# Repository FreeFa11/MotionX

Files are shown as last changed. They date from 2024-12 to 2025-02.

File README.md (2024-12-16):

# MotionControl
An input device that interprets your hand movement using IMU. MPU6050 with HMC5883L will be used for taking the input from hand movement as they are widely accessible and affordable. The aim of this project is to be able to implement all the important features and gestures from mouse and trackpads. If possible, we will also try to implement a touch screen like interaction.

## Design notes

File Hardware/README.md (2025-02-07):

# Schematics
This section has three parts.

- Enclosure : A 3D printable enclosure for keeping every electronic component together.
- Schematic : An schematic made using [KiCAD](https://www.kicad.org/).
- Simulation : An schematic of [LTSpice](https://www.analog.com/en/resources/design-tools-and-calculators/ltspice-simulator.html) for simulation of components.

The 3D printed enclosure has Body and Cover which is the case for housing all the electronic components. The Ring, Slider and Base are the moving parts that moves with your fingers which is assembled as shown in Assembled.png picture. The 3D design needs some improvement for better printable, strength and assembly.

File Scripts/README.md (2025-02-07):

# Scripts
All the scripts required during the development of this project are maintained here. The scripts include data collection, manipulation, visualisation and other simulations.

- Calibration : This folder contains the static data collection of accelerometer and calculation of all the parameters for calibration.
- Data Collection : This folder contains the script to capture data from serial port and parse the JSON string and upload it to the [Edge Impulse](https://edgeimpulse.com/).
- Data Preprocessing : This folder contains the scripts for analyzing the features of data.

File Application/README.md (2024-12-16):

# Application
This android application allows us to conveniently configure the device and also change some preferences and see how well the device is working. All the settings and preferences are managed through this application.

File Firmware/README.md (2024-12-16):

# Firmware
This section covers the firmware for MotionControl project.

- Microcontroller :     [ESP32S3 (N8R2)](https://www.espressif.com/en/products/socs/esp32-s3)
- Framework :           [PlatformIO](https://platformio.org/)
- Scheduler :           [FreeRTOS](https://www.freertos.org/)

## Structure
The structure is based on PlatformIO project environment.
- lib : Project specific libraries written by us
- include : Project Header files
- src : Project Source files
- test : Unit testing

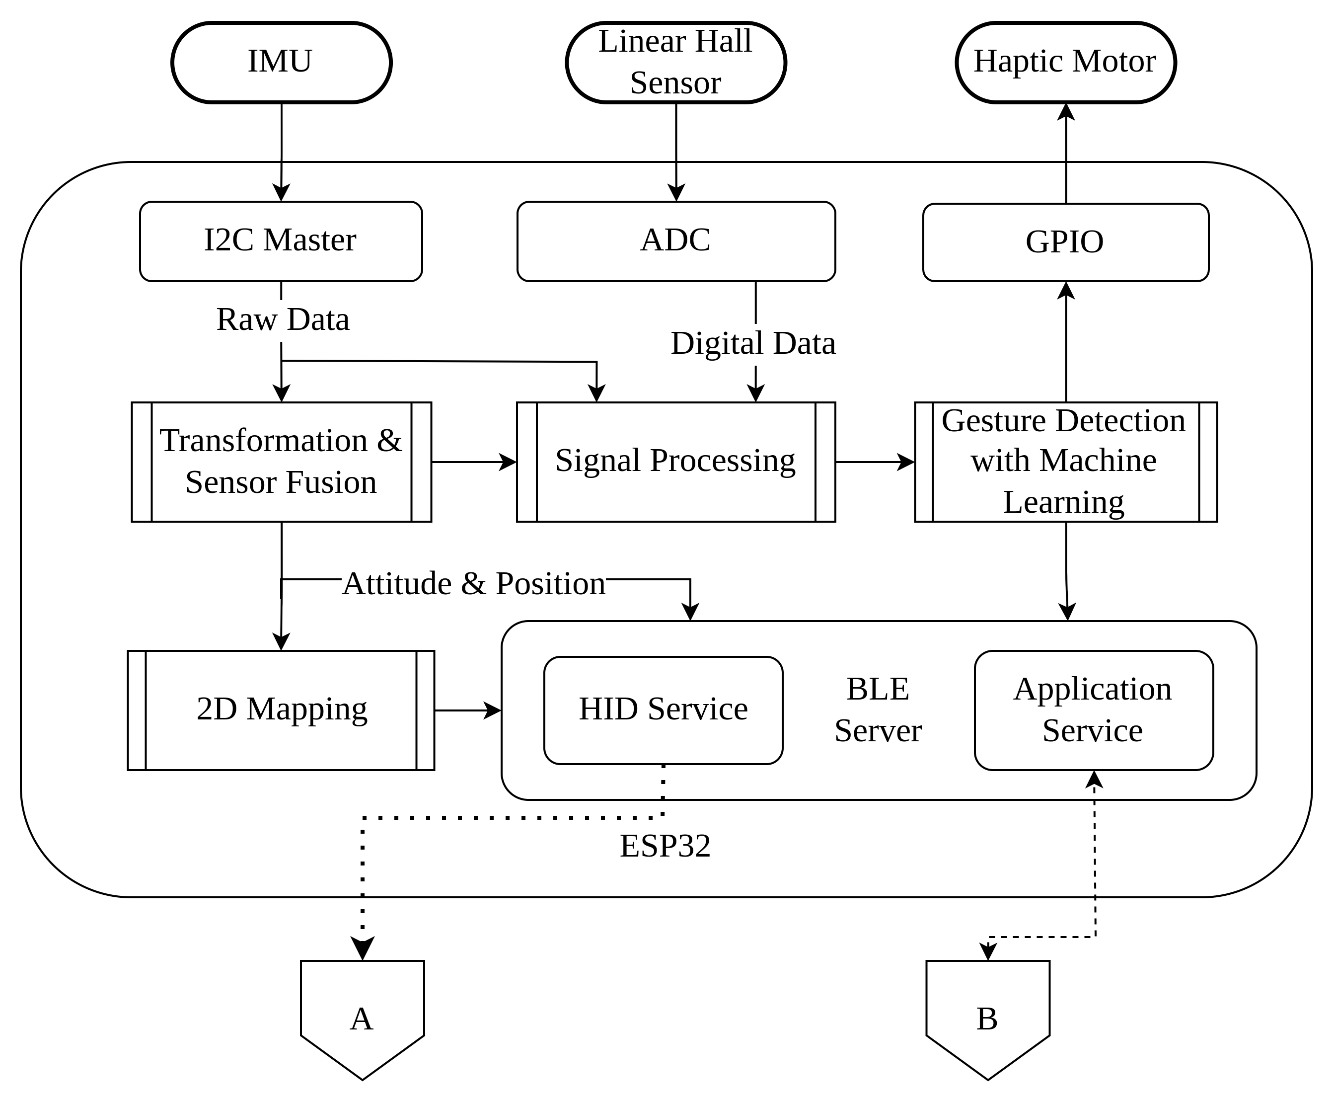
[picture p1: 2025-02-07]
Architecture/Microcontroller.png

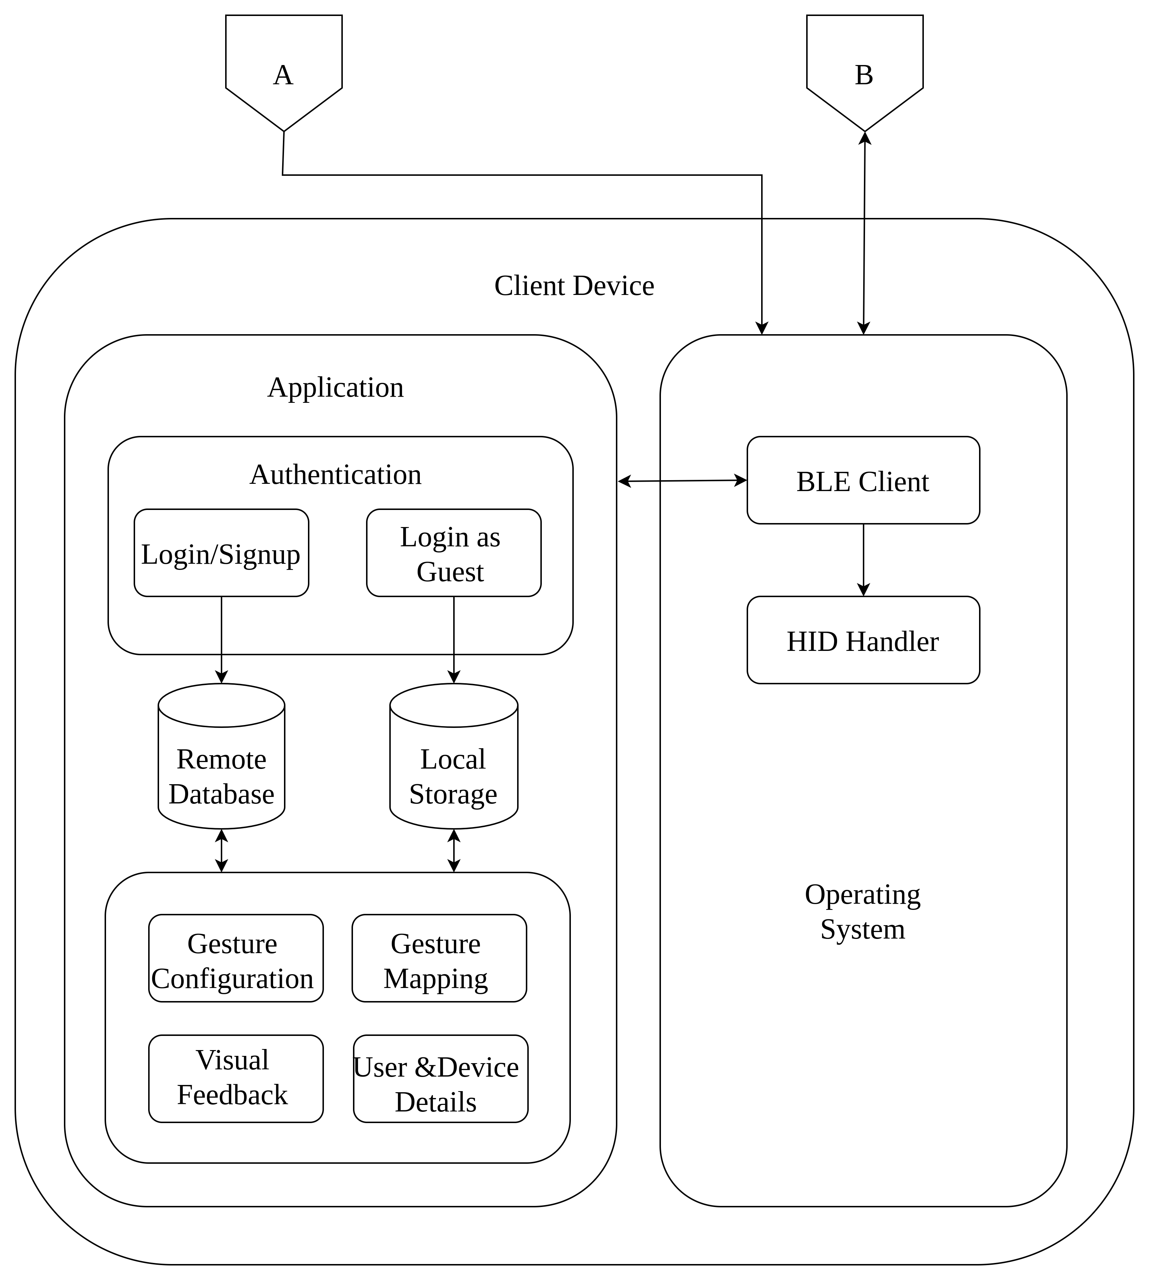
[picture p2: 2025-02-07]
Architecture/ControlledDevice.png

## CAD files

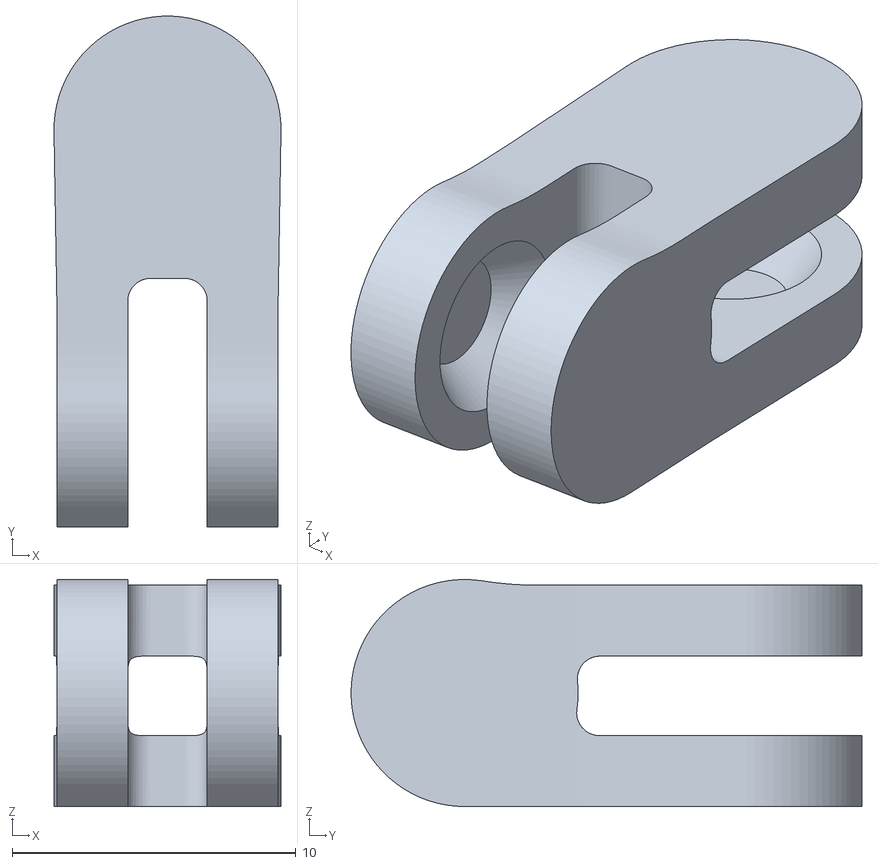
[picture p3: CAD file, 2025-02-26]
Hardware/Enclosure/Hinge.stl
8.00 x 18.0 x 8.00

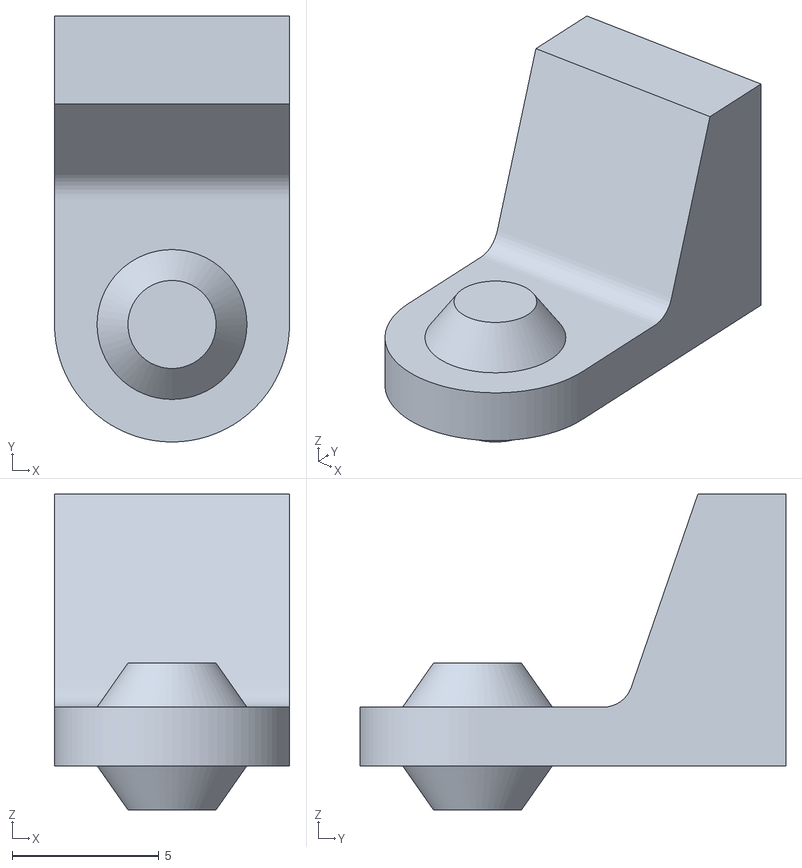
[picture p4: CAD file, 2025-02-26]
Hardware/Enclosure/Base.stl
8.00 x 14.5 x 10.8

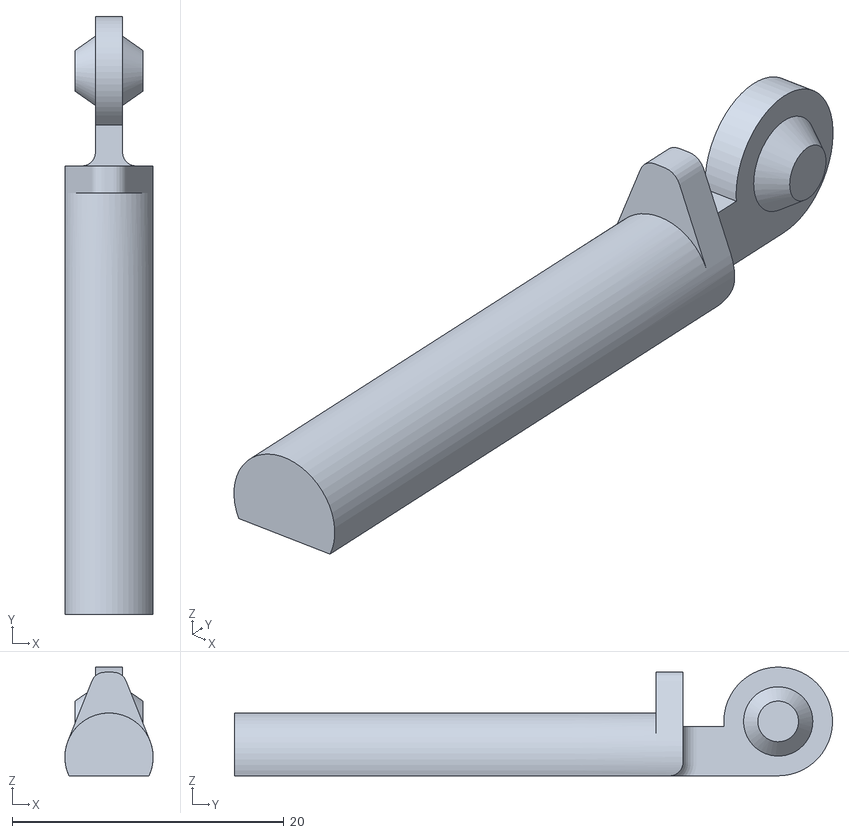
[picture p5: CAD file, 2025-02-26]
Hardware/Enclosure/Slider.stl
6.50 x 44.0 x 8.01

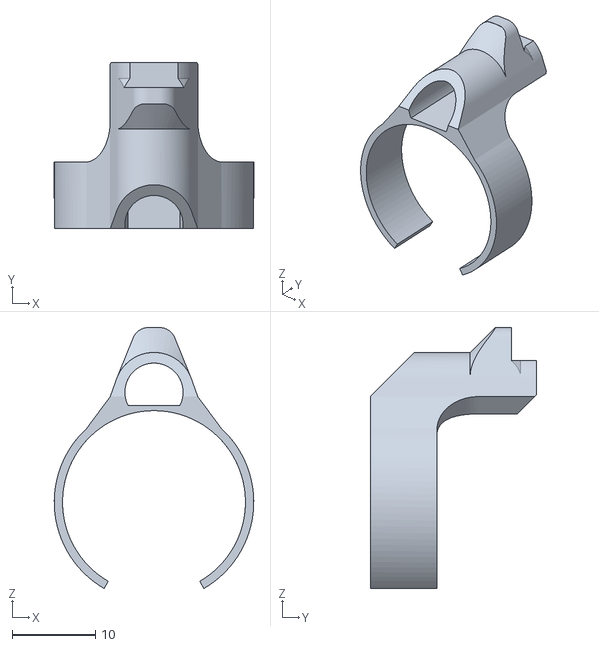
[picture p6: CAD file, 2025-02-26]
Hardware/Enclosure/Ring.stl
24.0 x 20.0 x 31.4

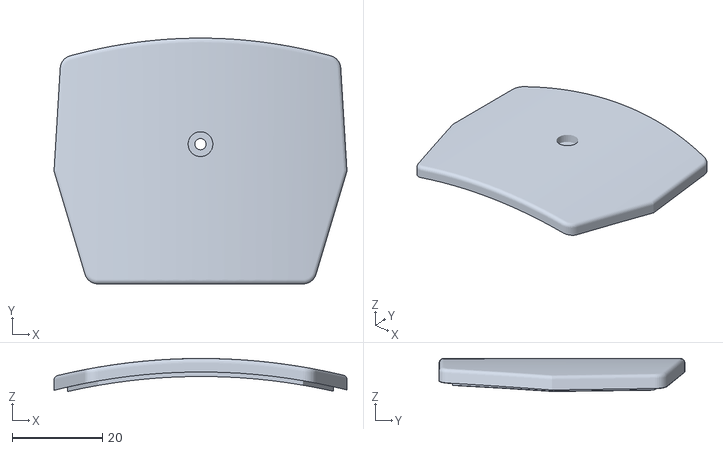
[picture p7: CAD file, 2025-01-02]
Hardware/Enclosure/Cover.stl
65.0 x 54.5 x 7.34

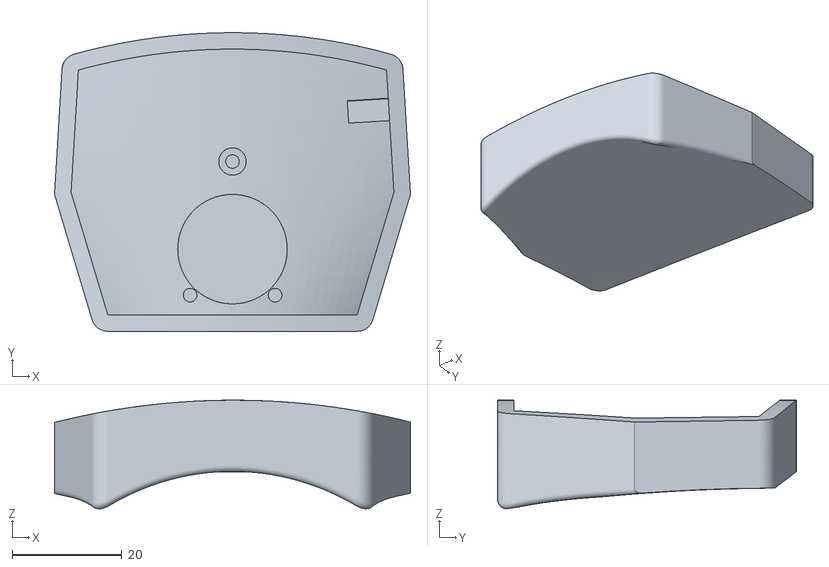
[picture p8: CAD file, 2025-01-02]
Hardware/Enclosure/Body.stl
65.0 x 54.5 x 19.8

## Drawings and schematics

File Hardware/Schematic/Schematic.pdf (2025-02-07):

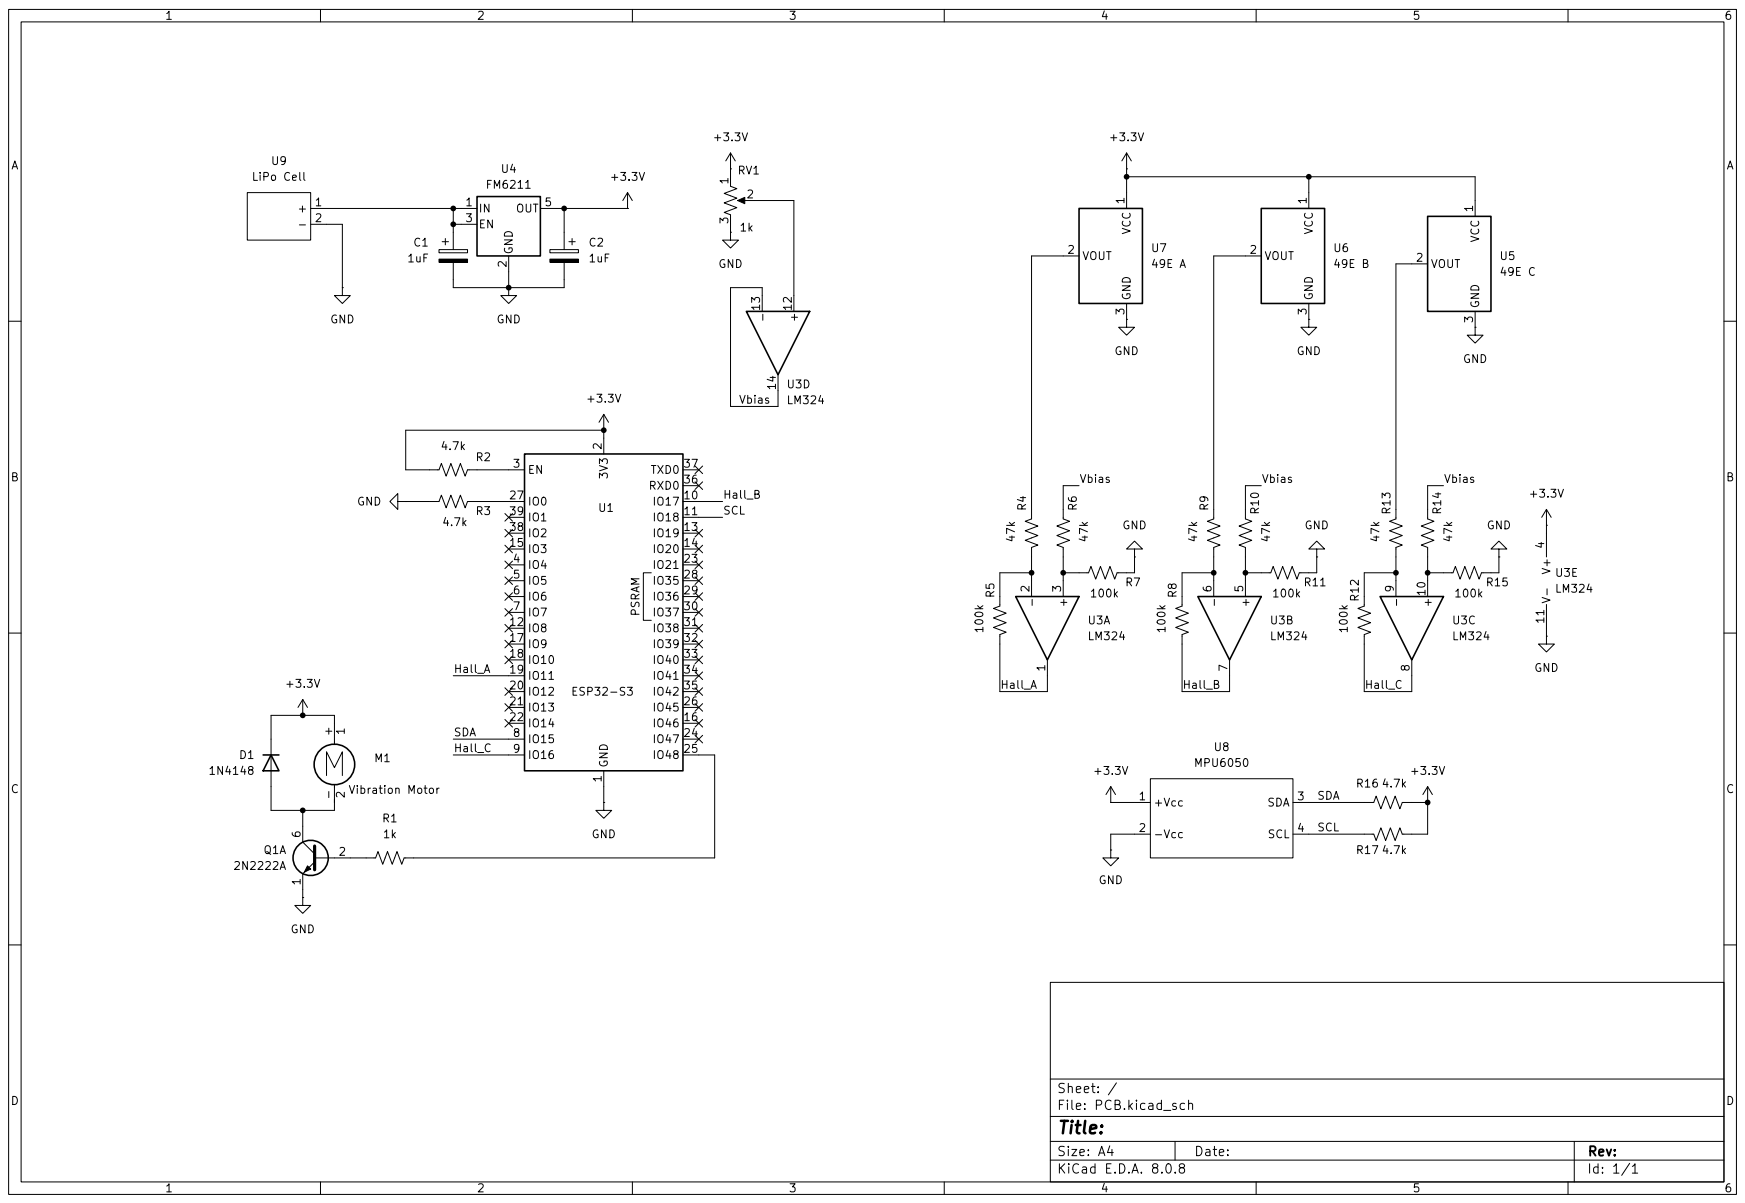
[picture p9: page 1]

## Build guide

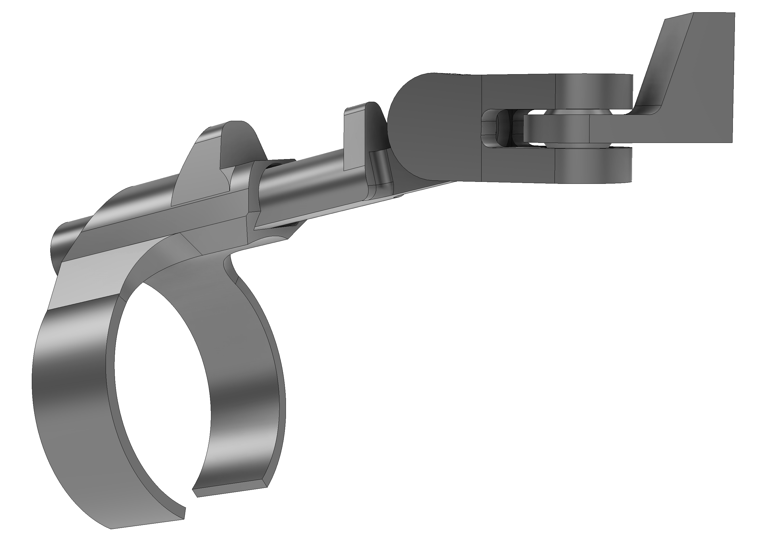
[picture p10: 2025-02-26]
Hardware/Enclosure/Assembled.png

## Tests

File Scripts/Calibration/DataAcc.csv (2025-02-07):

AX | AY | AZ
795.24 | 538.592 | 15935.92
-259.944 | 13770.8 | 8304.144
-195.456 | 14436.432 | 7219.168
-142.744 | 15156.984 | 5764.264
-216.864 | 15628.464 | 4377.688
-296.6 | 16051.016 | 2722.336
-431.136 | 16279.336 | 1163.336
-503.176 | 16347.904 | 397.848
183.6 | 14261.4 | 7078.872
158.52 | 14215.648 | 7653.48
46.712 | 14369.36 | 7376.816
-251.992 | 14848.528 | 6400.528
292.992 | 14467.872 | 7196.384
269.44 | 13569.752 | 8672.128
440.36 | 12854.296 | 9666.856
605.792 | 12329.696 | 10275.858
666.936 | 12050.968 | 10616.256
502.16 | 11479.232 | 11211.376
384.272 | 10756.144 | 11880.36
453.96 | 10470.144 | 12137.024
609.456 | 9876.472 | 12601.84
668.248 | 9333.504 | 12999.256
727.0 | 8665.576 | 13438.616
731.472 | 8316.6 | 13662.792
746.704 | 7748.512 | 13976.264
557.488 | 6792.008 | 14438.464
658.464 | 6075.424 | 14751.56
772.04 | 5595.76 | 14958.216
736.4 | 5072.744 | 15136.68
715.208 | 4392.984 | 15349.456
696.8 | 5070.496 | 15143.44
755.096 | 4985.122 | 15139.936
735.696 | 4082.224 | 15432.328
717.728 | 3632.168 | 15546.696
672.184 | 3021.4 | 15679.896
759.832 | 2147.28 | 15829.68
38.416 | 919.976 | 15942.112
322.576 | 685.328 | 15963.792
735.464 | 1222.304 | 15926.952
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

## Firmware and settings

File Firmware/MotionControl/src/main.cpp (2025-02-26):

// Includes
#include <Arduino.h>
#include <freertos/FreeRTOS.h>

#include <Sensor.h>
#include <Haptic.h>
#include <Wireless.h>
#include <ArduinoJson.h>



// Definitions
#define IndexUpTHRESHOLD      1000
#define IndexDownTHRESHOLD    400
#define MiddleUpTHRESHOLD     1300
#define MiddleDownTHRESHOLD   150
#define RingUpTHRESHOLD       1500
#define RingDownTHRESHOLD     300
uint32_t Ticks;
enum STATE {Default, AllPress, IndexPress, RingPress, IndexRelease, RingRelease};
enum SWIPE {Left, Right, Up, Down};
struct StateMachine
{
    STATE state;
};


// Objects
BLEHID myHID;
Sensor mySensor;
Haptic myHaptic;
StateMachine myState;
Preferences myPreference;


// Objects from Companion App
float Sensitivity = 1.0;
bool HapticOn = true;
Pattern HapticMode = Pattern::Subtle;
uint32_t GestureOne = 1, GestureTwo = 2, GestureThree = 3, GestureFour = 4, GestureFive = 5;


// Functions
void ReadSavedData();
void Map2D(Sensor &Sens, BLEHID &HD);
void Scroll(Sensor &Sens, BLEHID &HD);
void RunStateMachine(StateMachine &SM, Sensor SN, BLEHID &HD);
void RunSwipe(Sensor &Sens);
void Swipe(SWIPE Direction);
// void RunGesture();
void RunKeyboardCombo(uint32_t Combo);


// Tasks & Queues
QueueHandle_t HapticQueue;
TaskHandle_t HapticTaskHandle;
void HapticTask(void *param);
TaskHandle_t GestureTaskHandle;


void setup()
{
  USBSerial.begin(115200);
  
  // Initializations
  myHID.Initialize();
  myHaptic.Initialize();
  mySensor.InitializeIMU(ACCEL_FS::A2G, GYRO_FS::G500DPS);
  mySensor.InitializeHall();
  myState.state = STATE::Default;
  ReadSavedData();
  
  // Queue
  HapticQueue = xQueueCreate(1, sizeof(Pattern));
  // GestureQueue = xQueueCreate(1, sizeof(uint8_t));
  // FeaturesQueue = xQueueCreate(4, sizeof(Feature));
  
  // Tasks
  if (HapticOn)
  {
    xTaskCreatePinnedToCore(
      HapticTask,
      "HapticTask",
      1500,
      NULL,
      1,
      &HapticTaskHandle,
      0
    );
  }
  
  // xTaskCreatePinnedToCore(
  //   GestureTask,
  //   "GestureTask",
  //   20000,
  //   NULL,
  //   1,
  //   &GestureTaskHandle,
  //   1
  // );
  
}

void loop()
{
  // // State based on fingers data
  // RunGesture();
  RunStateMachine(myState, mySensor, myHID);
  Map2D(mySensor, myHID);

// ***************************************************Testing****************************************//

  // float Pitch, Roll, Yaw;
  // float GX, GY, GZ;
  // mySensor.UpdateData();
  // mySensor.GetRawData(&GX, &GY, &GZ);
  // mySensor.CalculateOrientation(&Pitch, &Roll, &Yaw);

  // USBSerial.print(">GX:");
  // USBSerial.println(GX);
  // USBSerial.print(">GY:");
  // USBSerial.println(GY);
  // USBSerial.print(">GZ:");
  // USBSerial.println(GZ);

  // JsonDocument DataToApp;
  // DataToApp["X"] = 0;
  // DataToApp["Y"] = 0;
  // DataToApp["Z"] = 0;
  // DataToApp["Pitch"] = Pitch;
  // DataToApp["Roll"] = Roll;
  // DataToApp["Yaw"] = Yaw;

  // std::string Datastring;
  // serializeJson(DataToApp, Datastring);
  // myHID.WriteToApp(Datastring);

  // vTaskDelay(10 / portTICK_RATE_MS);
}





// Tasks
void HapticTask(void *param)
{
  Pattern Data;

  while (1)
  {
    if (xQueueReceive(HapticQueue, &Data, 0) == pdTRUE)
    {
      myHaptic.Vibrate(Data);
    }

    vTaskDelay(10 / portTICK_RATE_MS);
  }
}


// State Machine
void RunStateMachine(StateMachine &SM, Sensor SN, BLEHID &HD)
{
  switch (SM.state)
  {

  case STATE::Default:
    if (analogRead(RingFingerPin) < RingDownTHRESHOLD)
    {
      SM.state = STATE::RingPress;
    }
    else if (analogRead(IndexFingerPin) < IndexDownTHRESHOLD)
    {
      SM.state = STATE::IndexPress;
    }
    break;

  case STATE::AllPress:
  xQueueSend(HapticQueue, &HapticMode, 1);
  while (analogRead(RingFingerPin) < RingUpTHRESHOLD)
  {
      // ***ALL PRESS***
      USBSerial.println("AllPress");
      // Continuous Action Begin // 
      HD.ClickLeft();
      Map2D(SN, HD); 
      // Action End // 

      vTaskDelay(10 / portTICK_PERIOD_MS);
    }
    SM.state = STATE::Default;
    break;

  case STATE::IndexPress:
    Ticks = xTaskGetTickCount();
    SM.state = STATE::IndexRelease;
    while (analogRead(IndexFingerPin) < IndexUpTHRESHOLD)
    {
      if ((analogRead(RingFingerPin) < RingDownTHRESHOLD) && (analogRead(MiddleFingerPin) < MiddleDownTHRESHOLD))
      {
        SM.state = STATE::AllPress;
        break;
      }

      // ***INDEX PRESS***
      USBSerial.println("IndexPress");
      // Continuous Action Begin // 
      // Action End // 

      vTaskDelay(10 / portTICK_PERIOD_MS);
    }
    break;
    
  case STATE::RingPress:
    Ticks = xTaskGetTickCount();
    SM.state = STATE::RingRelease;
    while (analogRead(RingFingerPin) < RingUpTHRESHOLD)
    {
        if ((analogRead(IndexFingerPin) < IndexDownTHRESHOLD) && (analogRead(MiddleFingerPin) < MiddleDownTHRESHOLD))
        {
          SM.state = STATE::AllPress;
          break;
        }
        else if (analogRead(MiddleFingerPin) < MiddleDownTHRESHOLD)
        {
            // ***DOUBLE PRESS***
            USBSerial.println("TwoPress");
            // Continuous Action Begin // 
            // This for Scroll
            // Action End // 
          }
          else
          {
            // ***SINGLE PRESS***
            USBSerial.println("OnePress");
            // Continuous Action Begin // 
            RunSwipe(mySensor);
            // Action End // 
        }
        
        vTaskDelay(10 / portTICK_PERIOD_MS);
    }
    break;

  case STATE::IndexRelease:
    if((xTaskGetTickCount() - Ticks) < 250)
      {
        // ***INDEX RELEASE***
        xQueueSend(HapticQueue, &HapticMode, 1);
        USBSerial.println("LeftClick");
        // Action Begin // 
        HD.ClickLeft();
        // Action End // 
      }
    SM.state = STATE::Default;
    break;

  case STATE::RingRelease:
    if((xTaskGetTickCount() - Ticks) < 250)
    {
        // ***RING RELEASE***
        xQueueSend(HapticQueue, &HapticMode, 1);
        USBSerial.println("RightClick");
        // Action Begin // 
        HD.ClickRight();
         // Action End // 
    }
    SM.state = STATE::Default;
    break;

  default:
    USBSerial.println("State Error!!");
    ESP.restart();
    break;
  }
}

// Functions
void ReadSavedData()
{
  myPreference.begin("AppData", true);

  if (myPreference.isKey("Sensitivity"))
  {
    Sensitivity = myPreference.getUInt("Sensitivity") / 100.f;
    HapticOn = myPreference.getBool("HapticOn");
    HapticMode = (Pattern)myPreference.getUInt("HapticMode");
  }

  if (myPreference.isKey("GestureOne"))
  {
    GestureOne = myPreference.getUInt("GestureOne");
    GestureTwo = myPreference.getUInt("GestureTwo");
    GestureThree = myPreference.getUInt("GestureThree");
    GestureFour = myPreference.getUInt("GestureFour");
    GestureFive = myPreference.getUInt("GestureFive");
  }

  myPreference.end();
}

void Map2D(Sensor &Sens, BLEHID &HD)
{
  static float Pitch, Roll, Yaw;
  static float GY, GZ, GX;
  static float X,Y;
  // static Feature thisFeature;

  Sens.UpdateData();
  // Sens.GetRawData(&thisFeature.AX, &thisFeature.AY, &thisFeature.AZ, &thisFeature.GX, &thisFeature.GY, &thisFeature.GZ);
  // xQueueSend(FeaturesQueue, &thisFeature, 0);
  
  Sens.CalculateOrientation(&Pitch, &Roll, &Yaw);
  Sens.GetRawData(&GX, &GY, &GZ);


  GY /= 800;
  GZ /= 500;
  if ((GY < 127.) && (GY > -127.))
  {
    Y = int8_t(-GY);
  }
  else if (GY)
  {
    Y = -127;
  }
  else
  {
    Y = 127;
  }
  if ((GZ < 127.) && (GZ > -127.))
  {
    X = int8_t(-GZ);
  }
  else if (GZ)
  {
    X = -127;
  }
  else
  {
    X = 127;
  }

  HD.Move(X * Sensitivity, Y * Sensitivity, 0);

  // Handle Data from App
  myHID.HandleAppData();
}

void Scroll(Sensor &Sens, BLEHID &HD)
{
  float Pitch, Roll, Yaw;
  Sens.CalculateOrientation(&Pitch, &Roll, &Yaw);

  HD.Move(0, 0, Pitch);
}

void RunSwipe(Sensor &Sens)
{
  float GX, GY, GZ;
  Sens.UpdateData();
  Sens.CalculateOrientation();
  Sens.GetRawData(&GX, &GY, &GZ);

  if (GZ > 20000)
  {
    Swipe(SWIPE::Left);
    vTaskDelay(150 / portTICK_RATE_MS);
  }
  else if (GZ < -20000)
  {
    Swipe(SWIPE::Right);
    vTaskDelay(150 / portTICK_RATE_MS);
  }
  else if (GY > 20000)
  {
    Swipe(SWIPE::Up);
    vTaskDelay(150 / portTICK_RATE_MS);
  }
  else if (GY < -20000)
  {
    Swipe(SWIPE::Down);
    vTaskDelay(150 / portTICK_RATE_MS);
  }

  vTaskDelay(10 / portTICK_RATE_MS);
}

void Swipe(SWIPE Direction)
{
  switch (Direction)
  {
  case SWIPE::Left:
    myHID.Press(MODIFIERKEY::LeftControl);
    myHID.Press(MODIFIERKEY::LeftGUI);
    myHID.Press(CONTROLKEY::RightArrow);
    myHID.SendKeys();
    myHID.Press(MODIFIERKEY::LeftControl);
    myHID.Press(MODIFIERKEY::LeftAlt);
    myHID.Press(CONTROLKEY::RightArrow);
    myHID.SendKeys();
    break;
  case SWIPE::Right:
    myHID.Press(MODIFIERKEY::LeftControl);
    myHID.Press(MODIFIERKEY::LeftGUI);
    myHID.Press(CONTROLKEY::LeftArrow);
    myHID.SendKeys();
    myHID.Press(MODIFIERKEY::LeftControl);
    myHID.Press(MODIFIERKEY::LeftAlt);
    myHID.Press(CONTROLKEY::LeftArrow);
    myHID.SendKeys();
    break;
  case SWIPE::Up:
    myHID.Press(MODIFIERKEY::LeftGUI);
    myHID.SendKeys();
  break;
  case SWIPE::Down:
    myHID.Press(MODIFIERKEY::LeftControl);
    myHID.Press(MODIFIERKEY::LeftAlt);
    myHID.Press("d");
    myHID.SendKeys();
    myHID.Press(MODIFIERKEY::LeftGUI);
    myHID.Press("d");
    myHID.SendKeys();
  break;
  
  default:
    break;
  }
}

// void RunGesture()
// {
//   if (xQueueReceive(GestureQueue, &Gesture, 1))
//   {
//     switch (Gesture)
//     {
//     case 1:
//       RunKeyboardCombo(GestureOne);
//       break;
//     case 2:
//       RunKeyboardCombo(GestureTwo);
//       break;
//     case 3:
//       RunKeyboardCombo(GestureThree);
//       break;
//     case 4:
//       RunKeyboardCombo(GestureFour);
//       break;
//     case 5:
//       RunKeyboardCombo(GestureFive);
//       break;
    
//     default:
//       break;
//     }
//   }
// }

void RunKeyboardCombo(uint32_t Combo)
{
  switch (Combo)
  {
  case 1:                                         // Alt + F4
    myHID.Press(MODIFIERKEY::LeftAlt);
    myHID.Press(CONTROLKEY::F4);
    myHID.SendKeys();
    break;
    case 2:                                       // Ctrl + H
    myHID.Press(MODIFIERKEY::LeftControl);
    myHID.Press("h");
    myHID.SendKeys();
    break;
    case 3:                                       // Ctrl + S
    myHID.Press(MODIFIERKEY::LeftControl);
    myHID.Press("s");
    myHID.SendKeys();
    break;
    case 4:                                       // Alt + Enter
    myHID.Press(MODIFIERKEY::LeftAlt);
    myHID.Press(CONTROLKEY::Enter);
    myHID.SendKeys();
    break;
    case 5:                                       // Backspace
    myHID.Press(CONTROLKEY::Backspace);
    myHID.SendKeys();
    break;
  
  default:
    break;
  }
}

// ****************************************************CaptureData***************************************************************//

// #include <Arduino.h>
// #include <freertos/FreeRTOS.h>

// #include <ArduinoJson.h>
// #include <Sensor.h>


// Sensor mySensor;

// void setup()
// {
//   USBSerial.begin(115200);

//   mySensor.InitializeIMU();
// }

// void loop()
// {
//   JsonDocument myData;

//   static float AX, AY, AZ;
//   static float GX, GY, GZ;

//   mySensor.UpdateData();
//   mySensor.GetRawData(&AX, &AY, &AZ, &GX, &GY, &GZ);

//   myData["AX"] = AX;
//   myData["AY"] = AY;
//   myData["AZ"] = AZ;
//   myData["GX"] = GX;
//   myData["GY"] = GY;
//   myData["GZ"] = GZ;


//   serializeJson(myData, USBSerial);
//   USBSerial.println();

//   vTaskDelay(10 / portTICK_RATE_MS);
// }

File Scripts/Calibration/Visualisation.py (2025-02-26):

# %% Importing
import pandas as pd
import matplotlib.pyplot as plt
from mpl_toolkits.mplot3d import Axes3D
from scipy.optimize import least_squares
import numpy as np
import os



# %%  Reading 
myData = pd.read_csv(f"{os.path.dirname(os.path.abspath(__file__))}/DataAcc.csv")
# myGyroData = pd.read_csv(f"{os.path.dirname(os.path.abspath(__file__))}/DataGyro.csv")


# *****************************************************************************************

# # %%
# fig, axes = plt.subplots(1, 2, figsize=(10, 4))

# axes[0].hist(myData["AX"], bins=40, edgecolor='black')
# axes[0].set_title("Accelerometer X Axis")

# axes[1].hist(myData["AY"], bins=40, edgecolor='black')
# axes[1].set_title("Gyroscope X Axis")

# # %%
# fig.supxlabel("Value")
# fig.supylabel("Frequency")
# fig.suptitle("Histograms of Noise", fontsize=14, fontweight="bold")
# # plt.legend()

# for text in fig.findobj(plt.Text): 
#     text.set_fontsize(15)
#     text.set_fontfamily("Times New Roman")

# plt.tight_layout()
# plt.show()

# *****************************************************************************************
# t = np.arange(0, 1000, 10)

# plt.rcParams["font.size"] = 14 
# plt.rcParams["font.family"] = "Times New Roman" 

# plt.plot(t, myData["GX"].head(100), label="Gyroscope X", color="blue")
# plt.plot(t, myData["GY"].head(100), label="Gyroscope Y", color="red")
# plt.plot(t, myData["GZ"].head(100), label="Gyroscope Z", color="green")

# plt.xlabel("Time (ms)")
# plt.ylabel("Output")
# plt.title("Bias of IMU")


# plt.legend()
# plt.tight_layout()
# plt.show()

# *****************************************************************************************


# fig2d, plots = plt.subplots(1, 3)

# fig3d = plt.figure()
# ax = fig3d.add_subplot(1, 1, 1, projection='3d')
# ax.scatter(myData["AX"], myData["AY"], myData["AZ"], c=myData["AZ"], cmap='viridis', marker='o')
# ax.set_xlabel("X Axis")
# ax.set_ylabel("Y Axis")
# ax.set_zlabel("Z Axis")
# ax.set_title("3D")

# plots[0].scatter(myData["AX"], myData["AY"], marker="*")
# plots[1].scatter(myData["AY"], myData["AZ"], marker="*")
# plots[2].scatter(myData["AZ"], myData["AX"], marker="*")


# plt.legend()
# plt.tight_layout()
# plt.show()


# ***********************************************************************
from scipy.optimize import least_squares

# Example: Assume your IMU data is stored in a dictionary `data`
AX, AY, AZ = myData["AX"], myData["AY"], myData["AZ"]
g = 16500  # Gravity magnitude in m/s²

# Stack accelerometer readings into Nx3 matrix
A = np.column_stack((AX, AY, AZ))

# Objective function: Minimize deviation from unit sphere
def error_func(params, A):
    # Unpack bias and scale/misalignment matrix
    b = params[:3]  # Bias (bx, by, bz)
    S_flat = params[3:]  # Scale and misalignment matrix (flattened)
    S = S_flat.reshape(3, 3)

    # Apply calibration: a_corrected = S @ (a - b)
    A_corrected = (A - b) @ S.T

    # Compute deviation from expected norm (should be ~1g)
    error = np.linalg.norm(A_corrected, axis=1) - g
    # error = magnitude = np.sqrt(A_corrected[:, 0]**2 + A_corrected[:, 1]**2 + A_corrected[:, 2]**2) - g
    return error

# Initial guess: No bias, identity matrix for scale/misalignment
init_params = np.zeros(3 + 9)
init_params[3:] = np.eye(3).flatten()

# Solve using least squares
result = least_squares(error_func, init_params, args=(A,))

# Extract optimized bias and scale/misalignment matrix
bias_opt = result.x[:3]
S_opt = result.x[3:].reshape(3, 3)

print("Optimized Bias:", bias_opt)
print("Optimized Scale/Misalignment Matrix:\n", S_opt)

# Apply calibration to the data
A_calibrated = (A - bias_opt) @ S_opt.T

# Extract calibrated AX and AY
AX_calibrated, AY_calibrated, AZ_calibrated = A_calibrated[:, 0], A_calibrated[:, 1], A_calibrated[:, 2]

# Plot Pre-Calibrated vs. Calibrated AX vs AY
Fig = plt.figure(figsize=(8, 6))


# Pre-Calibrated Data
plt.scatter(AY, AZ, color='red', alpha=0.5, label="Raw")

# Calibrated Data
plt.scatter(AY_calibrated, AZ_calibrated, color='blue', alpha=0.5, label="Calibrated")

plt.xlabel("AccelerometerY")
plt.ylabel("AccelerometerZ")
plt.legend()
plt.title("Raw vs. Calibrated")
for text in Fig.findobj(plt.Text):
    text.set_fontsize(15)
    text.set_fontfamily("Times New Roman")
plt.grid()
plt.show()


# ***********************************************************************
# GX, GY, GZ = myGyroData["GX"], myGyroData["GY"], myGyroData["GZ"]
# GXAV = np.average(GX)*np.ones(len(GX))
# GYAV = np.average(GY)*np.ones(len(GY))
# GZAV = np.average(GZ)*np.ones(len(GZ))
# timeAxis = np.linspace(0, 6, len(GX))


# fig, ax = plt.subplots(1, 3)

# ax[0].plot(timeAxis, GX)
# ax[0].plot(timeAxis, GXAV)
# ax[1].plot(timeAxis, GY)
# ax[1].plot(timeAxis, GYAV)
# ax[2].plot(timeAxis, GZ)
# ax[2].plot(timeAxis, GZAV)

# print(f"GyroX: {np.average(GX)}, GyroY: {np.average(GY)}, GyroZ: {np.average(GZ)}")

# plt.tight_layout()
# plt.grid()
# plt.show()

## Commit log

2024-12-21 Improved Sensor Integration and Calibration
2025-01-02 Printable Enclosure and Simulation Schematic
    [Body.stl, Cover.stl]
2025-01-12 Very basic, unstable working Mouse
    [main.cpp]
2025-02-07 Accelerometer Calibration
    [DataAcc.csv]
2025-02-07 Updated Hardware and Architecture
    [Base.stl, Body.stl, Cover.stl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]
2025-02-26 Updated 3D design for strength
    [Base.stl, Hinge.stl, Ring.stl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]
2025-02-26 Major Firmware Change & Calibration
